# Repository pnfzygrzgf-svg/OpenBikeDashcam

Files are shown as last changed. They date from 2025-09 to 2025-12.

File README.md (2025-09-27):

----- Das ist die erste, veröffentlichte Version der Dashcam. Sie enthält noch ein paar Bugs und Verbesserungsmöglichkeiten, die demnächst bearbeitet werden ---------  

# OpenBikeDashcam - Kurzbeschreibung
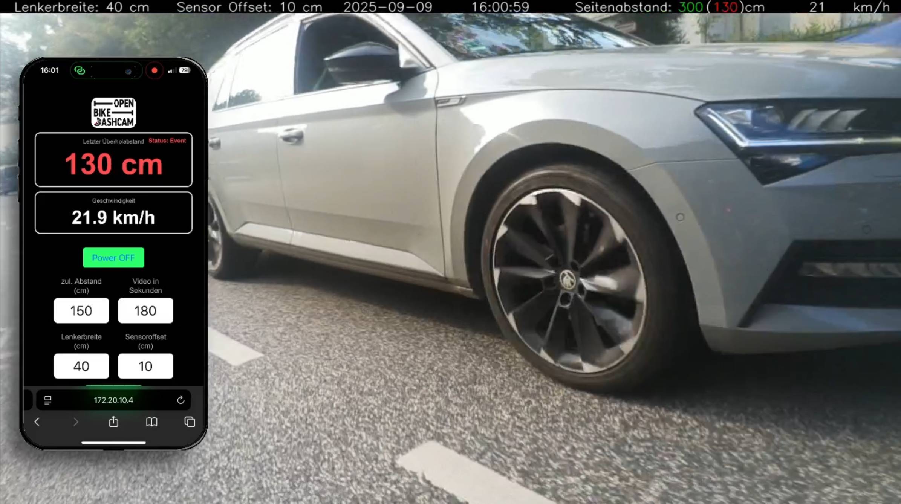
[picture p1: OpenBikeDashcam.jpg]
Dashcam


Das Projekt besteht aus einer Dashcam fürs Fahrrad, die Videos des rückwärtigen und seitlichen Verkehrs aufnimmt. Zusätzlich wird mit einem Abstandssensor der Überholabstand der vorbeifahrenden Autos ermittelt und im Video angezeigt. Folgende Funktionen sind bereits integriert: 

- Videoaufnahme in Sequenzen von einstellbarer Länge (z.B. 30Sekunden)  
- Speicherung auf USB Stick nur, wenn während der Aufnahmezeit eines Segmentes der Sicherheitsabstand unterschritten wurde. sonst wird das Segment gelöscht.  
- Einstellungen von zulässigem Abstand, Lenkerbreite, Länge der Videosequenzen, Versatz des Sensors von der Fahrradmitte ist über txt Dateien auf dem USB stick oder über die WebApp mögich
- Sollten auf dem USB Stick weniger als 100mb Speicherplatz verbleiben, wird das letzte Video gelöscht (Status LED zeigt das durch blau farbe an)
- Zu jedem Video wird eine CSV Datei mit GPS Daten, Zeit und Abstand gespeichert.

# Ausblick: demnächst verfügbare Funktionen  
- weitere Fahrradcomputer-Funktionen in der WebApp (Max-Geschwindigkeit, Durchschnittsgeschwindigkeit, Fahrzeit, Fahrstecke in km. Alles seit dem letzten Programmstart und seit Inbetriebnahme der Dashcam)
- bisher gibt es noch kein Gehäuse für die Dashcam. Die Entwicklung ist aber in Arbeit. 

# Lizenz
Software: GNU GENERAL PUBLIC LICENSE Version 3, 29 June 2007  
Hardware: CERN Open Hardware Licence Version 2 - Strongly Reciprocal

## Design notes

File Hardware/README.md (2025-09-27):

# Komponenten: 
Anschlussschema der Dashcam Komponenten  

1) Raspberry Pi cm5 (das compute module, wegen der Baugröße. Der Protoyp läuft auf der Version 8GB RAM mit 32GB emmc, aber ein kleiner sollte auch reichen)
2) Waveshare CM5 Nano-IO Board (A) - (also nur USB-C und USB-A anschluss)
3) Raspberry pi camera module 3 wide
4) 2 x rgb led modul für die Status- und Rücklicht LED (z.B. ky-016 FZ0455)
5) 4 x Widerstände für die LEDs (z.B. 330 Ohm) 
6) Sparkfun XM125 A121
7) USB Stick (möglichst USB 3)
8) RTC Batterie RPI-RTCBAT von Berry Base
9) ggf. Powerbank mit mind. 5V, 5A oder ein passendes Netzteil

## Zubehör
10) qwiic kabel (qwiic stecker female auf Dupont stecker female)
11) 6 jumper Kabel (female)
12) USB Kabel für die Powerbank
13) Kamerakabel ( 22-polig/0,5 mm Pitch zu 15-polig/1,0 mm Pitch)

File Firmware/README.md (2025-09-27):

# Installation der Open Bike Dashcam auf dem Raspberry Pi compute module 5

Das CM5 hat kein Display. Daher erfolgt die Installation ohne direkt angeschlossenes Display. 

# Raspberry Pi einrichten 
1) OS Full 64-bit (inkl. Desktop) mit dem Raspberry Pi Imager installieren https://www.raspberrypi.com/software/
2) Pi Starten, warten bis er sich mit dem Wlan verbunden hat und z.B. über die FritzBox Weboberfläche die IP des Pi finden.
3) über putty oder ssh in Windows mit Pi verbinden (hierfür die IP des Pi notwendig)
4) VNC aktivieren:  
    4.1 `sudo raspi-config`  
    4.2 Interface -> VNC -> yes  
5) Rasperry neu starten. mit RealVC oder TigerVNC den auf die Weboberfläche zugreifen
6) alle updates installieren  (Terminal öffnen):  
   `sudo apt-get update`
7) notwendige Systempakete installieren:  
`sudo apt install -y python3-pip python3-dev python3-venv libopenblas-dev liblapack-dev libatlas-base-dev gfortran libjpeg-dev libtiff-dev libpng-dev libavcodec-dev libavformat-dev libswscale-dev libv4l-dev libx264-dev libx265-dev libgtk2.0-dev libcanberra-gtk3-module libblas-dev libhdf5-dev libimath-dev libopenexr-dev libgstreamer1.0-dev libgstreamer-plugins-base1.0-dev libx11-dev libxext-dev libxtst-dev libgl1-mesa-glx libglu1-mesa-dev`  
8) `sudo apt-get install libavformat-dev libavcodec-dev libavdevice-dev libavutil-dev libavfilter-dev libswscale-dev libswresample-dev`
9) virtuelle Umgebung (venv) im Projektordner anlegen:  
	   `python3 -m venv --system-site-packages venv`
10) virtuelle Umgebung aktivieren:  
	   `source venv/bin/activate`
11) Pip aktualisieren:  
	   `pip install --upgrade pip`

ab hier: alles, was mit "pip" startet passiet im Terminal, in dem die Venv aktiv ist. Parallel zweites Terminal ohne Venv öffnen. Dort wird alles andere insalliert.

12) notwendige Python Bibliotheken installieren:  
    in dieser Reihenfolge nacheinander:  
      `pip install numpy`  
      `pip install opencv-python`  
      `sudo apt install libcap-dev`  (im Standard Terminal)  
      `pip install picamera2 lgpio RPi.GPIO`
## Kamera einrichten
14) Kamera einrichten:
  
    13.1 Kameraerkennung aktivieren:  
        `sudo nano /boot/firmware/config.txt` (Datei wird geöffnet)  
  
    13.2 folgende Zeile suchen:  
        `camera_auto_detect=1`  
        diese Zeile löschen oder auskommentieren und statt dessen folgendes eingeben:  
        
        start_x=1
        camera_auto_detect=0
        dtoverlay=imx708,cam1
        
    13.3 danach strg-o, Enter, strg-x (speichern, schließen)  
    13.4 pi neu starten  
    13.5 Kameras anzeigen lassen
    	`libcamera-hello --list-cameras`  
		Ausgabe sollte wie folgt sein: 
		   
		   pi@RaspberryCM5:~ $ libcamera-hello --list-cameras
		   Available cameras
		   -----------------
		   0 : imx708_wide [4608x2592 10-bit RGGB
		   (/base/axi/pcie@1000120000/rp1/i2c@70000/imx708@1a)
		   Modes: 'SRGGB10_CSI2P' : 1536x864 [120.13 fps - (768, 432)/3072x1728 crop]
                             2304x1296 [56.03 fps - (0, 0)/4608x2592 crop]
                             4608x2592 [14.35 fps - (0, 0)/4608x2592 crop]

    13.6 Kamera testen
		    `libcamera-hello`

       hier sollte sich kurz ein live-Vorschaubild der Kamera öffnen  
	
 15) RGPIO installieren (in der venv):
     14.1 Venv wieder aktivieren: `source venv/bin/activate`
		   `pip install rpi-lgpio`  
 15)weitere Pakete installieren:
	15.1 `sudo apt-get install python3-libcamera python3-kms++`  (Standard Terminal Fenster ohne venv)
    15.2 `sudo apt-get install libcamera-dev` (außerhalb der venv)
	15.3  `pip install rpi-libcamera`  (in der venv - kann lange dauern)

## Sensor Einrichten
16) Sensor XM125 einrichten:  
	16.1 anschließen wie folgt
    
	| Farbe   | Funktion | Pin [Board nummeriert] |
	| ------- | -------- | ---------------------- |
	| schwarz | GND      | Pin 6                  |
	| Rot     | 5V       | Pin 4                  |
	| Blau    | SDA      | Pin 3 (GPIO2)          |
	| Gelb    | SCL      | Pin 5 (GPIO3)          |  
  
	16.2 ic2 aktivieren:  
		sudo raspi-config --> interface options -> i2c  
	16.3 i2c tools installieren:  
		`sudo apt install -y i2c-tools`  
	16.4 prüfen, ob der Sensor erkannt wird:  
		`i2cdetect -y 1`  
   		--> sollte Adresse 0x52 erkennen  
	16.5 (optional): falls man mit dem Sensor und der Arudino IDE rumspielen möchte ARduino IDE installieren

		sudo apt update
		sudo apt install arduino

      16.5.1 pip3 install smbus2
   
## Sensor Einrichten für Distance_Detector
unter Windows den Sensor per USB anschließen:  
	16.6 https://pypi.org/project/acconeer-exptool/ herunterladen  
	16.7 Entpacken  
	16.8 update.bat ausführen (dauert lange)  
	16.9 run.bat ausführen - exploration Tool startet  
	16.10 auf reiter "flash" wechseln (links)  
	16.11 Sensor vorbereiten: Boot gedrückt halten - reset kurz drücken - boot loslassen  
	16.12 com-port des sensors aus gerätemanager suchen (z.B. com7)     
    	Falls der Sensor beim Einstecken **nicht als "USB Serial Port"** im **Geräte-Manager** auftaucht, installiere den passenden **CH340-USB-Treiber**: https://learn.sparkfun.com/tutorials/how-to-install-ch340-drivers/all  
	16.13 aus dem sdk-ordner-out die i2c_detector_distance.bin Datei suchen  
	16.14 im browse menü die .bin datei auswählen  
	16.15 Sensor einstellen und auf flashen drücken --> firmware wird auf den sensor geladen  
	16.16 reset button 1x drücken  
	16.17 Sensor vom strom nehmen. beim Neustart startet die neue Firmware

# Dashcam Software einrichten (auf dem Raspberry):  
17) die folgenden Dateien/Ordner in den Ordner home/pi/venv verschieben:

    - Dashcam.py  
    - gps_receiver.py  
    - den Ordner "static"

18) den Ordner "settings" auf den USB Stick verschieben (ohne Unterverzeichnis)  
19) Testen des Programms:  
    19.1 venv aktivieren:  

		source venv/bin/activate

	19.2 Programm starten:  

		python3 venv/Dashcam.py

20) Datei im Autostart hinterlegen:  
	20.1 über folgenden Befehl einen sudo Dateiexplorer öffnen:  

		sudo pcmanfm

	20.2 dann die Datei "Dashcam.service" in den Ordner "/etc/systemd/system/" kopieren  
    20.3 Service-Datei aktivieren:
    
	- `sudo systemctl daemon-reload`   
	- `sudo systemctl enable Dashcam.service`  
	- optional: (Zum sofortigen Starten des Programms) `sudo systemctl start Dashcam.service`
 	- optional: (zum stoppen des Programms) `sudo systemctl stop Dashcam.service`

# RTC einrichten:
21) RTC einrichten:  
	21.1 `sudo nano /boot/firmware/config.txt` öffnen
	21.1 dort die folgende Zeil einfügen: 
	
		dtparam=rtc_bbat_vchg=3000000

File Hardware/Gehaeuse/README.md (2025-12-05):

## Teile

1. **StandardMountAdapter** (OpenBikeSensor)    
   https://github.com/openbikesensor/OpenBikeSensor3dPrintableCase/blob/main/export/Mounting/StandardMountAdapter.stl

2. **SeatPostMount** (OpenBikeSensor)  
   https://github.com/openbikesensor/OpenBikeSensor3dPrintableCase/blob/main/export/Mounting/SeatPostMount.stl

3. **Box, Deckel und CM5-Halterung**  
   STL-Datei(en):  
   - `Box.stl`  
   - `Deckel.stl`  
   - `CM5-Halterung.stl`

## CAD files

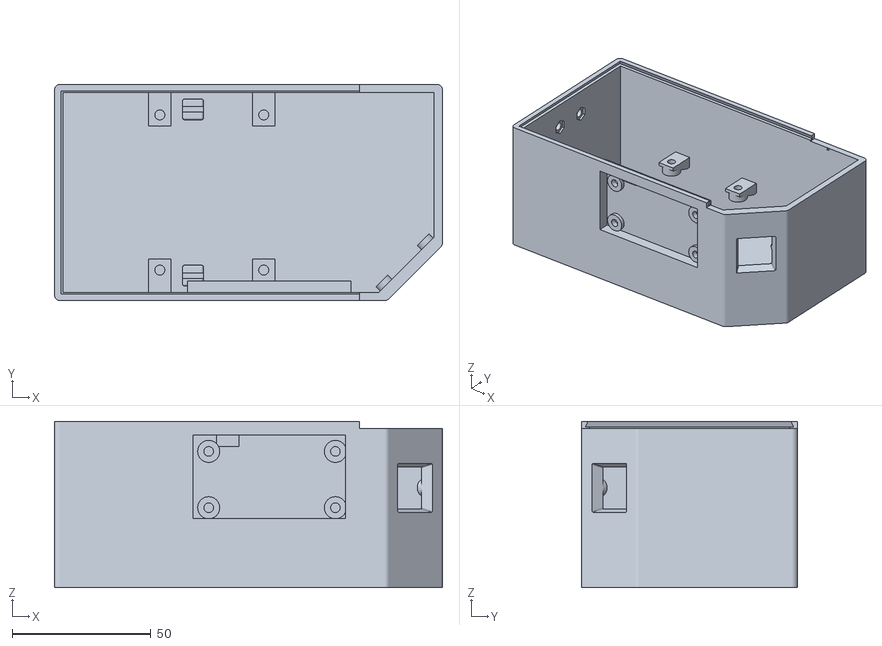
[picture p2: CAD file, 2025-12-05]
Hardware/Gehaeuse/box.stl
140.0 x 78.0 x 60.0

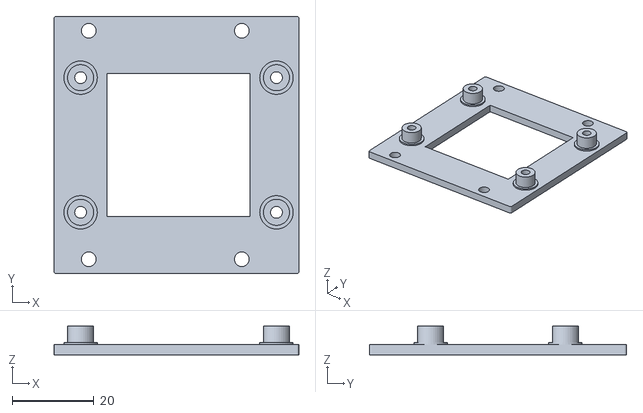
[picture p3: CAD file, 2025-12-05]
Hardware/Gehaeuse/cm5-halterung.stl
60.0 x 63.0 x 7.01

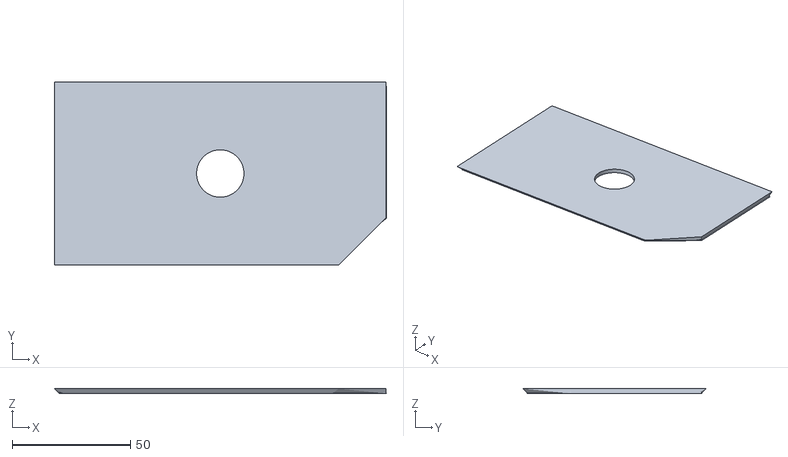
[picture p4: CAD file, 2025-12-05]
Hardware/Gehaeuse/deckel.stl
140.2 x 77.4 x 2.01

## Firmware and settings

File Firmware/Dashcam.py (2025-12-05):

#!/usr/bin/env python3

#License: GNU GENERAL PUBLIC LICENSE Version 3, 29 June 2007

import sys
import time
import threading
import queue
import multiprocessing
from multiprocessing import Process, Value, Manager
from ctypes import c_int
from datetime import datetime
import os
import shutil
import csv
import cv2
import numpy as np
from picamera2 import Picamera2
import smbus2
import lgpio
import logging
import logging.handlers
import signal
#für GPS empfang
from gps_receiver import gps_generator
#für WebApp Anzeige auf dem iPhone
from flask import Flask, jsonify, render_template_string, request
app = Flask(__name__)
import logging
log = logging.getLogger('werkzeug')
log.setLevel(logging.ERROR)  # nur Fehler anzeigen, keine normalen Requests
#für die Variable shared_event_state
from ctypes import c_bool      
from ctypes import c_int      

shared_event_state = Value(c_bool, False)
shared_distance = Value('i', 300)  # Anfangswert
shared_abstand = Value('i', 300)   # gefilterter Abstand
shared_bike_width = Value(c_int, 0)    # Lenkerbreite (Standardwert)
shared_sensor_offset = Value(c_int, 0) # Sensoroffset (Standardwert)
shared_overlay_update_flag = Value(c_bool, True)  # updateanweisung für das statische Overlay. Init auf True damit Overlay beim Start gezeichnet wird
######## ASYNCHRONES LOGGING SETUP ########
log_queue = queue.Queue(-1)
queue_handler = logging.handlers.QueueHandler(log_queue)
console_handler = logging.StreamHandler()
formatter = logging.Formatter('[%(asctime)s] %(message)s', datefmt='%H:%M:%S')
console_handler.setFormatter(formatter)
logger = logging.getLogger()
logger.setLevel(logging.INFO)
logger.addHandler(queue_handler)
queue_listener = logging.handlers.QueueListener(log_queue, console_handler)
queue_listener.start()

######## GLOBAL SETTINGS ########
FRAME_WIDTH = 1280
FRAME_HEIGHT = 720
FPS = 30
shared_dist_zul = Value(c_int, 150)             # Anfangswert für dist_zul (Abstandsschwelle)
shared_partial_video_seconds = Value(c_int, 180) # Anfangswert für PARTIAL_VIDEO_SECONDS
SD_PATH = "/dev/shm"
EVENT_DIR_NAME = "Events"
USB_BASE_PATH = "/media/pi"
RED_PIN = 6      # Board Pin 31
GREEN_PIN = 16   # Board Pin 36
BLUE_PIN = 26    # Board Pin 37
RUECKLICHT_PIN = 5
XSHUT_PIN = 23
h = lgpio.gpiochip_open(0)
lgpio.gpio_claim_output(h, XSHUT_PIN)

shutdown_flag = threading.Event()

######## LED CONTROL ########
class LedController(threading.Thread):
    def __init__(self, red_pin, green_pin, blue_pin):
        super().__init__()
        self.red_pin = red_pin
        self.green_pin = green_pin
        self.blue_pin = blue_pin
        self._stop_event = threading.Event()
        self.blink_interval = 0.6
        self.chip = lgpio.gpiochip_open(0)
        for pin in [self.red_pin, self.green_pin, self.blue_pin]:
            lgpio.gpio_claim_output(self.chip, pin)
            lgpio.gpio_write(self.chip, pin, 0)
        # Farbzustand
        #self.red_state = 0
        self.green_state = 0
        self.blue_state = 0
        self._blink = threading.Event()
        self._running = threading.Event()

    def set_color(self, red, green, blue):
        self.red_state = red
        self.green_state = green
        self.blue_state = blue


    def set_blink_interval(self, interval):
        self.blink_interval = interval

    def set_on(self):
        self._blink.clear()
        self._running.set()

    def set_blink(self):
        self._running.clear()
        self._blink.set()

    def set_off(self):
        self._running.clear()
        self._blink.clear()

    def stop(self):
        self._stop_event.set()

    def run(self):
        while not self._stop_event.is_set():
            if self._blink.is_set():
                lgpio.gpio_write(self.chip, self.red_pin, self.red_state)
                lgpio.gpio_write(self.chip, self.green_pin, self.green_state)
                lgpio.gpio_write(self.chip, self.blue_pin, self.blue_state)
                time.sleep(self.blink_interval / 2)
                lgpio.gpio_write(self.chip, self.red_pin, 0)
                lgpio.gpio_write(self.chip, self.green_pin, 0)
                lgpio.gpio_write(self.chip, self.blue_pin, 0)
                time.sleep(self.blink_interval / 2)
            elif self._running.is_set():
                lgpio.gpio_write(self.chip, self.red_pin, self.red_state)
                lgpio.gpio_write(self.chip, self.green_pin, self.green_state)
                lgpio.gpio_write(self.chip, self.blue_pin, self.blue_state)
                time.sleep(0.05)
            else:
                lgpio.gpio_write(self.chip, self.red_pin, 0)
                lgpio.gpio_write(self.chip, self.green_pin, 0)
                lgpio.gpio_write(self.chip, self.blue_pin, 0)
                time.sleep(0.1)
        # LEDs ausschalten beim Stoppen
        lgpio.gpio_write(self.chip, self.red_pin, 0)
        lgpio.gpio_write(self.chip, self.green_pin, 0)
        lgpio.gpio_write(self.chip, self.blue_pin, 0)
        lgpio.gpiochip_close(self.chip)


######### Sensor & I2C etc. ##########
# === XM125 Sensor Register & Funktionen ===
I2C_ADDR = 0x52
REG_DETECTOR_STATUS = 0x0003
REG_DISTANCE_RESULT = 0x0010
REG_PEAK0_DISTANCE = 0x0011
REG_PEAK0_STRENGTH = 0x001B
REG_START = 0x0040
REG_END = 0x0041
REG_MAX_PROFILE = 0x0045
REG_THRESHOLD_METHOD = 0x0046
REG_FIXED_THRESHOLD_VALUE = 0x0049
REG_THRESHOLD_SENSITIVITY = 0x004A
REG_COMMAND = 0x0100
CMD_APPLY_CONFIG_AND_CALIBRATE = 1
CMD_MEASURE_DISTANCE = 2
CMD_RECALIBRATE = 5

def get_usb_label():
    try:
        entries = os.listdir(USB_BASE_PATH)
        for entry in entries:
            full_path = os.path.join(USB_BASE_PATH, entry)
            if os.path.ismount(full_path):
                return entry
    except Exception as e:
        logger.error(f"USB-Laufwerk-Fehler: {e}")
    return None

def set_leds(red=None, green=None, blue=None, ruecklicht=None):
    # Wird nicht mehr extern zum direkten GPIO-Zugriff genutzt,
    # LedController steuert GPIO exklusiv.
    pass

def write_reg(bus, addr: int, value: int):
    data = [
        (addr >> 8) & 0xFF,
        addr & 0xFF,
        (value >> 24) & 0xFF,
        (value >> 16) & 0xFF,
        (value >> 8) & 0xFF,
        value & 0xFF,
    ]
    msg = smbus2.i2c_msg.write(I2C_ADDR, data)
    bus.i2c_rdwr(msg)

def read_reg(bus, addr: int) -> int:
    addr_bytes = [(addr >> 8) & 0xFF, addr & 0xFF]
    write = smbus2.i2c_msg.write(I2C_ADDR, addr_bytes)
    read = smbus2.i2c_msg.read(I2C_ADDR, 4)
    bus.i2c_rdwr(write, read)
    result = list(read)
    return (result[0] << 24) | (result[1] << 16) | (result[2] << 8) | result[3]

def wait_until_not_busy(bus):
    while True:
        status = read_reg(bus, REG_DETECTOR_STATUS)
        if (status & 0x80000000) == 0:
            break
        time.sleep(0.01)

def configure_sensor(bus):
    write_reg(bus, REG_START, 300)
    write_reg(bus, REG_END, 4000)
    write_reg(bus, REG_MAX_PROFILE, 3)
    write_reg(bus, REG_THRESHOLD_METHOD, 3)
    write_reg(bus, REG_THRESHOLD_SENSITIVITY, 500)
    write_reg(bus, 0x0049, 25000)
    write_reg(bus, 0x0048, 50)
    write_reg(bus, 0x004C, 30000)
    write_reg(bus, 0x0043, 1)
    write_reg(bus, 0x0044, 15000)
    write_reg(bus, 0x0047, 2)
    write_reg(bus, 0x004B, 2)
    write_reg(bus, 0x0080, 0)
    write_reg(bus, REG_COMMAND, CMD_APPLY_CONFIG_AND_CALIBRATE)
    wait_until_not_busy(bus)

def measure_distance(bus):
    write_reg(bus, REG_COMMAND, CMD_MEASURE_DISTANCE)
    wait_until_not_busy(bus)
    result = read_reg(bus, REG_DISTANCE_RESULT)
    if result & 0x00000400:
        return None, None
    if result & 0x00000200:
        write_reg(bus, REG_COMMAND, CMD_RECALIBRATE)
        wait_until_not_busy(bus)
        return None, None
    num_peaks = result & 0xF
    if num_peaks == 0:
        return None, None
    distance = int(round(read_reg(bus, REG_PEAK0_DISTANCE) / 10))
    strength = read_reg(bus, REG_PEAK0_STRENGTH)
    return distance, strength

def sensor_worker(shared_distance, shared_bike_width, shared_sensor_offset):
    bus = smbus2.SMBus(1)
    try:
        configure_sensor(bus)
        logger.info("Sensor konfiguriert.")
        while True:
            dist, _ = measure_distance(bus)
            if dist is not None:
                shared_distance.value = int(round(dist - ((shared_bike_width.value / 2) - shared_sensor_offset.value)))
            else:
                shared_distance.value = 300
            time.sleep(1/FPS)
    except Exception as e:
        logger.error(f"Sensorfehler: {e}")
        shared_distance.value = 300


def create_dirs(base_path, event_path):
    os.makedirs(base_path, exist_ok=True)
    os.makedirs(event_path, exist_ok=True)
    logger.info(f"Speicherordner: {base_path}, {event_path}")

def get_bike_width_cm(filename):
    try:
        with open(filename, 'r') as file:
            val = file.read().strip()
            return int(val) if val.isdigit() else 0
    except:
        return 0

def get_sensor_offset_cm(filename):
    try:
        with open(filename, 'r') as file:
            val = file.read().strip()
            return int(val) if val.isdigit() else 0
    except:
        return 0

def get_dist_zul(path):
    try:
        with open(path, 'r') as f:
            val = f.read().strip()
            return int(val) if val.isdigit() else 150
    except Exception:
        return 150

def get_partial_video_seconds(path):
    try:
        with open(path, 'r') as f:
            val = f.read().strip()
            return int(val) if val.isdigit() else 60
    except Exception:
        return 60

######## ASYNCHRONE SPEICHERUNG (SAVE-WORKER) ########

save_queue = queue.Queue()

def get_free_space_bytes(path):
    """Gibt freien Speicherplatz (Bytes) im angegebenen Pfad zurück."""
    st = os.statvfs(path)
    return st.f_bavail * st.f_frsize

def delete_oldest_files(folder, ext_video=".mp4", ext_csv=".csv"):
    """Löscht das älteste Video + entsprechende CSV basierend auf Dateiendungen."""
    files = [f for f in os.listdir(folder) if f.endswith(ext_video)]
    if not files:
        return False
    files_full = [(f, os.path.getctime(os.path.join(folder, f))) for f in files]
    files_full.sort(key=lambda x: x[1])
    oldest_video = files_full[0][0]
    base_name = oldest_video[:-len(ext_video)]
    video_path = os.path.join(folder, oldest_video)
    csv_path = os.path.join(folder, base_name + ext_csv)
    try:
        if os.path.exists(video_path):
            os.remove(video_path)
        if os.path.exists(csv_path):
            os.remove(csv_path)
        logger.info(f"Lösche älteste Dateien: {oldest_video} und {base_name + ext_csv}")
        return True
    except Exception as e:
        logger.error(f"Fehler beim Löschen ältester Dateien: {e}")
        return False

def save_worker(led_ctrl):
    led_state_blue = False
    while True:
        task = save_queue.get()
        if task is None:
            break
        writer_path, csv_path, is_event, event_path = task
        try:
            # Bei Event-Videos: Dateien umbenennen mit EVENT_ Präfix
            if is_event:
                old_video_name = os.path.basename(writer_path)
                old_csv_name = os.path.basename(csv_path)
                
                # Nur umbenennen wenn noch nicht EVENT_ Präfix vorhanden
                if not old_video_name.startswith("EVENT_"):
                    new_video_name = f"EVENT_{old_video_name}"
                    new_csv_name = f"EVENT_{old_csv_name}"
                    
                    new_writer_path = os.path.join(os.path.dirname(writer_path), new_video_name)
                    new_csv_path = os.path.join(os.path.dirname(csv_path), new_csv_name)
                    
                    # Umbenennen in /dev/shm
                    if os.path.exists(writer_path):
                        os.rename(writer_path, new_writer_path)
                        writer_path = new_writer_path
                    if os.path.exists(csv_path):
                        os.rename(csv_path, new_csv_path)
                        csv_path = new_csv_path
            
            free_bytes = get_free_space_bytes(event_path)
            if free_bytes < 100 * 1024 * 1024:
                if not led_state_blue:
                    led_ctrl.set_color(0, 0, 1)  # blau
                    led_state_blue = True
                deleted = delete_oldest_files(event_path)
                if not deleted:
                    logger.warning("Kein altes Video zum Löschen gefunden bei wenig Speicher.")
            else:
                if led_state_blue:
                    led_ctrl.set_color(1, 0, 0)  # rot
                    led_state_blue = False

            # IMMER speichern - alle Videos in event_path
            destination = os.path.join(event_path, os.path.basename(writer_path))
            shutil.move(writer_path, destination)
            shutil.move(csv_path, os.path.join(event_path, os.path.basename(csv_path)))
            
            if is_event:
                logger.info(f"EVENT-Video gesichert: {os.path.basename(writer_path)}")
            else:
                logger.info(f"Video gesichert: {os.path.basename(writer_path)}")
                
        except Exception as e:
            logger.error(f"Fehler im Save-Worker: {e}")
        save_queue.task_done()

######## VIDEO WRITER THREAD ########
class VideoWriterThread(threading.Thread):
    def __init__(self, filename, frame_size, fps, fourcc='mp4v'):
        super().__init__()
        self.filename = filename
        self.queue = queue.Queue(maxsize=120)
        self.stopped = threading.Event()
        self.writer = cv2.VideoWriter(
            filename,
            cv2.VideoWriter_fourcc(*fourcc),
            fps,
            frame_size
        )

    def run(self):
        while not self.stopped.is_set() or not self.queue.empty():
            try:
                frame = self.queue.get(timeout=0.05)
                self.writer.write(frame)
                self.queue.task_done()
            except queue.Empty:
                continue
        self.writer.release()

    def write(self, frame):
        try:
            self.queue.put(frame, timeout=0.2)
        except queue.Full:
            logger.warning("[WARNING] VideoWriter-Queue voll. Frame wurde verworfen!")

    def stop(self):
        self.stopped.set()
        self.queue.join()

def make_writer_thread(is_event=False):
    prefix = "EVENT_" if is_event else ""
    fname = f"{SD_PATH}/{prefix}{datetime.now().strftime('%Y-%m-%d_%H-%M-%S')}.mp4"
    writer_thread = VideoWriterThread(fname, (FRAME_WIDTH, FRAME_HEIGHT), FPS)
    writer_thread.start()
    return writer_thread, fname


def stop_and_queue_save(writer_thread, csv_file, is_event, writer_path, csv_path, event_path):
    # Schließen der CSV-Datei sofort
    csv_file.close()
    # Writer im Hintergrund stoppen lassen (nicht blockieren)
    writer_thread.stop()
    # Übergibt direkt die Dateien in die Save-Queue -> Save-Worker erledigt den Rest
    save_queue.put((writer_path, csv_path, is_event, event_path))


def gps_worker_process(gps_data_dict, interval=1): #Messinterval = 1s
    """
    Startet den GPS-Generator aus gps_receiver.py und schreibt
    die gemessenen GPS-Daten zyklisch in gps_data_dict.
    Interval in Sekunden bestimmt die Aktualisierungshäufigkeit.
    """
    gen = gps_generator()
    try:
        for data in gen:
            gps_data_dict['timestamp'] = int(time.time() * 1000)
            gps_data_dict['lat'] = data.get('latitude', 0.0)
            gps_data_dict['lon'] = data.get('longitude', 0.0)
            speed_knots = data.get('speed_knots', 0.0)
            gps_data_dict['speed'] = speed_knots * 1.852  # Knoten -> km/h
            gps_data_dict['heading'] = data.get('course', 0.0)
            time.sleep(interval)
    except KeyboardInterrupt:
        pass
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

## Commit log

2025-12-05 Gehäuse STL
    [box.stl, cm5-halterung.stl, deckel.stl]
2025-12-05 Box STL korrigiert
    [box.stl]
